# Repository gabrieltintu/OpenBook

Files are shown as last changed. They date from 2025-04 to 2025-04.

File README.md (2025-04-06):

## © 2025 Gabriel-Claudiu TINTU

# OpenBook - E-Book Reader Project

## Table of Contents

1. [Block Diagram](#block-diagram)
2. [Bill of Materials (BOM)](#bill-of-materials-bom)
3. [Hardware Functionality and Components](#hardware-functionality-and-components)
   - [Main Controller](#main-controller)
   - [Display System](#display-system)
   - [Power Management](#power-management)
   - [Memory and Storage](#memory-and-storage)
   - [Sensors and Timing](#sensors-and-timing)
   - [Connectivity](#connectivity)
4. [ESP32-C6 Pin Usage](#esp32-c6-pin-usage)
5. [3D Representation](#3d-representation)

## Block Diagram

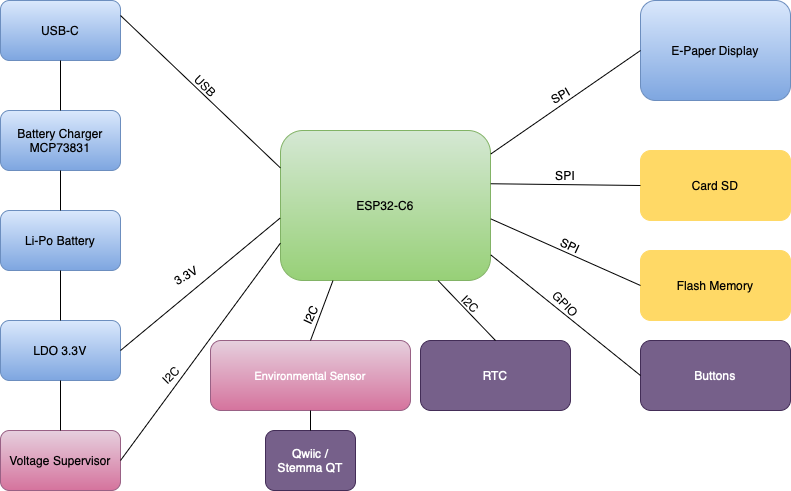
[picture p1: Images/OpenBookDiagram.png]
Block Diagram


## Bill of Materials (BOM)
| Package | Parts | Datasheet | Supplier  |
|---|---|---|---|
| ADAFRUIT_CHIP-LED0603 | CHG_LED | [Link](https://eu.mouser.com/datasheet/2/216/AP1608SURCK-71562.pdf) | [Link](https://eu.mouser.com/ProductDetail/Kingbright/AP1608SURCK?qs=VdjlWU%2FzoOEvYrd0H0exvQ%3D%3D) |
| SJ | SJ1 | [Link](https://grabcad.com/library/solder-jumpers-1) | [Link](https://grabcad.com/library/solder-jumpers-1) |
| ESP32_WROVER_EAGLE-LTSPICE_R0402 | R1_PWRUSB, R1, R1_PINH1, R2-PINH, R2-PINH1, R5, R6, R7, R8, R9, R10, R_BOOT, R_CL1, R_RESET, R3, R1_PINH, R4, R_CHANGE, R_CAPACITOR, R2, R1_BAT, R2_BAT, R2_USB, R2_USB1 | [Link](https://eu.mouser.com/datasheet/2/447/YAGEO_PYu_RC_Group_51_RoHS_L_12-3313492.pdf) | [Link](https://eu.mouser.com/ProductDetail/YAGEO/RC0402FR-07100KL?qs=mnq%2FyloZIXzTlUn7JAHSWg%3D%3D) |
| ESP32_WROVER_EAGLE-LTSPICE_C0402 | C1, C2, C4_USB, C6, C8, C9, C10, C_DELAY, EPD_C5, EPD_C1, EPD_C2, EPD_C6, EPD_C7, EPD_C8, EPD_C9, EPD_C10, EPD_C11, EPD_C12, C7, C5, C4, C1_BAT, C1_BAT1, C1_BAT2, C2_BAT, C5_USB | [Link](https://eu.mouser.com/datasheet/2/447/upy_gphc_x5r_4v_to_50v-3461255.pdf) | [Link](https://eu.mouser.com/ProductDetail/YAGEO/CC0402MRX5R5BB106?qs=zEY9bCHj09eCmUJdZuS5Lg%3D%3D) |
| RCL_CT3528 | C3 | [Link](https://eu.mouser.com/datasheet/2/40/TAJ-3165264.pdf) | [Link](https://eu.mouser.com/ProductDetail/KYOCERA-AVX/TAJB475K025RNJ?qs=mgX5NEyWO4Sl7CIvkz4Jiw%3D%3D) |
| 112ATAARR03ATTEND | J4 | [Link](https://store.comet.bg/download-file.php?id=27596) | [Link](https://store.comet.srl.ro/Catalogue/Product/43497/) |
| ESP32_WROVER_SPARKFUN-DISCRETESEMI_SOT23-3 | Q1, Q2 | [Link](https://www.diodes.com/assets/Datasheets/DMG2305UX.pdf) | [Link](https://eu.mouser.com/ProductDetail/Diodes-Incorporated/DMG2305UX-7?qs=L1DZKBg7t5F%2FNBHrjfxC%252Bg%3D%3D) |
| IND_4828-WE-TPC_WRE | L1 | [Link](https://www.we-online.com/components/products/datasheet/744043680.pdf) | [Link](https://eu.mouser.com/ProductDetail/Wurth-Elektronik/744043680?qs=PGXP4M47uW6VkZq%252BkzjrHA%3D%3D) |
| SOT95P280X125-5N | IC1 | [Link](https://fscdn.rohm.com/en/products/databook/datasheet/ic/power/voltage_detector/bd52xxg-e.pdf) | [Link](https://eu.mouser.com/ProductDetail/ROHM-Semiconductor/BD5229G-TR?qs=4kLU8WoGk0vvnhrrYwdszw%3D%3D) |
| MYBUTTON | BOOT_BUTTON, CHANGE_BUTTON, RESET_BUTTON | [Link](https://www3.panasonic.biz/ac/e_download/control/switch/light-touch/catalog/sw_lt_eng_3529s_side.pdf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) | [Link](https://eu.mouser.com/ProductDetail/Panasonic/EVQ-P7L01P?qs=rJ%252BziJWpyszWhhNszc02jQ%3D%3D) |
| CAPCP3225X100N | C10_SUPERCAP | [Link](https://eu.mouser.com/datasheet/2/360/Seiko_Instruments_MicroBattery_E_20230330_2024Jan_-3561061.pdf) | [Link](https://eu.mouser.com/ProductDetail/Seiko-Semiconductors/CPH3225A?qs=3etwrb1wR%252BhUOph6lAO7eg%3D%3D) |
| SOIC127P1032X265-16N | U3 | [Link](https://eu.mouser.com/datasheet/2/609/DS3231-3421123.pdf) | [Link](https://eu.mouser.com/ProductDetail/Analog-Devices-Maxim-Integrated/DS3231SN?qs=1eQvB6Dk1vhUlr8%2FOrV0Fw%3D%3D) |
| XCVR_ESP32-C6-WROOM-1-N8 | U2 | [Link](https://eu.mouser.com/datasheet/2/891/Espressif_ESP32_C6_WROOM_1__Datasheet_V0_1_PRELIMI-3239987.pdf) | [Link](https://eu.mouser.com/ProductDetail/Espressif-Systems/ESP32-C6-WROOM-1-N8?qs=8Wlm6%252BaMh8ST02Gmwp74cw%3D%3D) |
| ESP32C6_VARISTOR_CT/CN1812 | PFMF.050.1 | [Link](https://eu.mouser.com/datasheet/2/358/typ_PFMF-1275918.pdf) | [Link](https://eu.mouser.com/ProductDetail/Schurter/PFMF.050.2?qs=1auRipcfynCums5v1iucSA%3D%3D) |
| ESP32_WROVER_AVX---SD0805S020S1R0_AVX_SD0805S020S1R0_0 | D2, D7 | [Link](https://eu.mouser.com/datasheet/2/40/schottky-3165252.pdf) | [Link](https://eu.mouser.com/ProductDetail/KYOCERA-AVX/SD0805S020S1R0?qs=jCA%252BPfw4LHbpkAoSnwrdjw%3D%3D) |
| ESP32_WROVER_BME680_PSON80P300X300X100-8N | SENSOR2 | [Link](https://www.bosch-sensortec.com/media/boschsensortec/downloads/datasheets/bst-bme680-ds001.pdf) | [Link](https://store.comet.srl.ro/Catalogue/Product/50164/) |
| ESP32_WROVER_SPARKFUN-IC-POWER_SOT23-5 | U0 | [Link](https://eu.mouser.com/datasheet/2/268/MCP73831_Family_Data_Sheet_DS20001984H-3441711.pdf) | [Link](https://eu.mouser.com/ProductDetail/Microchip-Technology/MCP73831T-4ADI-OT?qs=hH%252BOa0VZEiBTiqxSV9eepQ%3D%3D) |
| FH34SRJ24S05SH99 | J1 | [Link](https://eu.mouser.com/datasheet/2/760/xc6220-3371556.pdf) | [Link](https://eu.mouser.com/ProductDetail/Torex-Semiconductor/XC6220A331MR-G?qs=AsjdqWjXhJ8ZSWznL1J0gg%3D%3D) |
| SON50P200X200X80-9N | U4 | [Link](https://eu.mouser.com/datasheet/2/609/MAX17048_MAX17049-3469099.pdf) | [Link](https://eu.mouser.com/ProductDetail/Analog-Devices-Maxim-Integrated/MAX17048G%2bT10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) |
| SOD3716X135N | D3, D4, D5 | [Link](https://eu.mouser.com/datasheet/2/40/schottky-3165252.pdf) | [Link](https://eu.mouser.com/ProductDetail/KYOCERA-AVX/SD0805S020S1R0?qs=jCA%252BPfw4LHbpkAoSnwrdjw%3D%3D) |
| DIOC1608X36N | D6, D8, D9, D10, D11, D12 | [Link](https://www.littelfuse.com/assetdocs/pulseguard-esd-suppressors-pgb1-datasheet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) | [Link](https://eu.mouser.com/ProductDetail/Littelfuse/PGB1010603MR?qs=gu7KAQ731URLg4GSnNNN7Q%3D%3D) |
| JST04_1MM_RA | J3 | [Link](https://eu.mouser.com/datasheet/2/813/Qwiic_Connector_Datasheet-1223982.pdf) | [Link](https://eu.mouser.com/ProductDetail/SparkFun/PRT-14417?qs=wd5RIQLrsJhgdz%2FpmZ%2F3GQ%3D%3D) |
| SAMACSYS_PARTS_USB4110GFA | J2 | [Link](https://eu.mouser.com/datasheet/2/837/GCT_USB4110_Product_Drawing___20k_cycles-3455479.pdf) | [Link](https://eu.mouser.com/ProductDetail/GCT/USB4110-GF-A?qs=KUoIvG%2F9IlYiZvIXQjyJeA%3D%3D) |
| SOT65P210X110-3N | Q3 | [Link](https://www.vishay.com/doc?63399) | [Link](https://eu.mouser.com/ProductDetail/Vishay-Semiconductors/SI1308EDL-T1-GE3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) |
| SOT95P280X145-6N | D1 | [Link](https://eu.mouser.com/datasheet/2/389/usblc6_2sc6y-1852505.pdf) | [Link](https://eu.mouser.com/ProductDetail/STMicroelectronics/USBLC6-2SC6Y?qs=gNDSiZmRJS%2FOgDexvXkdow%3D%3D) |
| SON127P600X800X80-9N | U1 | [Link](https://eu.mouser.com/datasheet/2/949/Winbond_W25Q512JV_Datasheet-3240039.pdf) | [Link](https://eu.mouser.com/ProductDetail/Winbond/W25Q512JVEIQ?qs=l7cgNqFNU1jw6svr3at6tA%3D%3D) |
| SOT95P280X120-5N | IC4 | [Link](https://eu.mouser.com/datasheet/2/760/xc6220-3371556.pdf) | [Link](https://eu.mouser.com/ProductDetail/Torex-Semiconductor/XC6220A331MR-G?qs=AsjdqWjXhJ8ZSWznL1J0gg%3D%3D) |

## Hardware Functionality and Components

### Main Controller

* ESP32-C6-WROOM-1-N8: The core microcontroller module that manages all device functions

### Display System

* E-Paper Display: Connected via a 24-pin FH34SRJ-24S-0.5SH connector (J1)
* E-Paper Drive Circuit: Custom circuitry for driving the e-paper display
* Display Type Selector: Allows for configuration of different e-paper display types

### Power Management

* LDO Voltage Regulator (XC6220A331MR-G): Provides regulated 3.3V power supply for the system
* Battery Charge Controller (MCP73831): Manages charging of the Li-Po battery
* Battery Charge Level Monitor (MAX17048G+T10): Monitors battery charge level and status
* USB C Connector: For power input and data communication
* ESD Protection (USBLC6-2SC6Y): Protects USB data lines from electrostatic discharge

### Memory and Storage

* External NOR Flash (W25Q512JVEIQ): 64MB flash memory for data storage
* SD Card Slot: For expandable storage

### Sensors and Timing

* Environmental Sensor (BME688): Measures temperature, humidity, pressure, and gas resistance
* RTC Module (DS3231SN): Real-time clock for accurate timekeeping

### Connectivity

* Qwiic/Stemma QT Connector: For I2C-based expansion modules
* USB-C: For data communication and power

## ESP32-C6 Pin Usage

| **Pin** | **Function** | **Component** | **Purpose** |
|-----|---|---|---|
| EN  | RESET | Reset button | System reset input |
| IO0 | INT_RTC | RTC | RTC interrupt for timing events |
| IO1 | 32KHZ | RTC | 32kHz clock signal from RTC |
| IO2 | MISO | SPI Bus | Data input from SPI peripherals |
| IO3 | EPD_BUSY | E-Paper Display | Monitor display ready status |
| IO4 | SS_SD | SD Card | SD card chip select |
| IO5 | EPD_DC | E-Paper Display | Display data/command selection |
| IO6 | SCK | SPI Bus | SPI clock signal |
| IO7 | MOSI | SPI Bus | Data output to SPI peripherals |
| IO8 | GPIO8 | General Purpose | Auxiliary functions |
| IO9 | IO/BOOT | Boot button | Boot mode selection |
| IO10 | EPD_CS | E-Paper Display | Display chip select |
| IO11 | FLASH_CS | External NOR Flash | Flash memory chip select |
| IO12 | USB_D- | USB Interface | USB data negative line |
| IO13 | USB_D+ | USB Interface | USB data positive line |
| IO15 | IO/CHANGE | Change button | Status change detection |
| IO16/TXD0 | TX | Serial Debug | UART transmit |
| IO17/RXD0 | RX | Serial Debug | UART receive |
| IO18 | RTC_RST | RTC | RTC reset control |
| IO19 | I2C_PW | I2C Bus | I2C devices power control |
| IO20 | EPD_3V3_C | E-Paper Display | Display power control |
| IO21 | SDA | I2C Bus | I2C data line |
| IO22 | SCL | I2C Bus | I2C clock line |
| IO23 | EPD_RST | E-Paper Display | Display reset control |

## 3D Representation

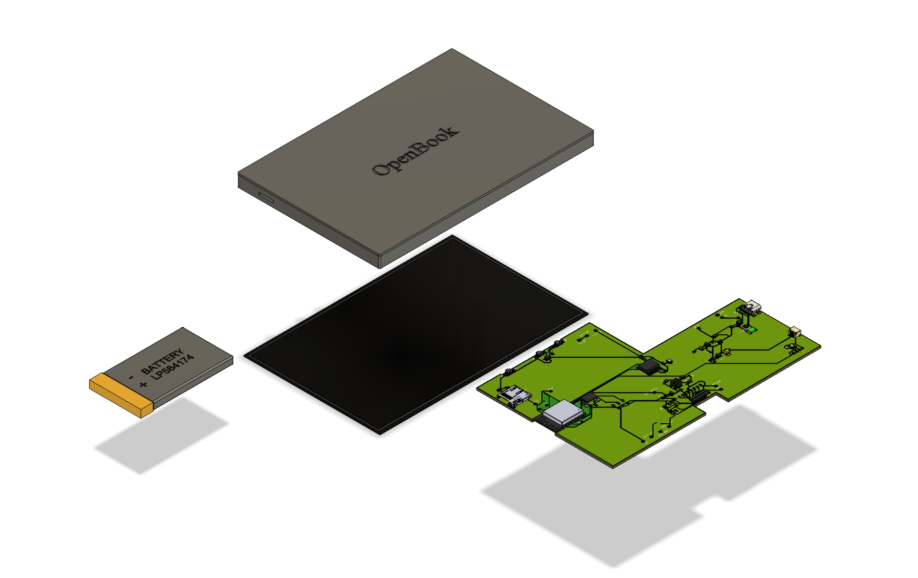
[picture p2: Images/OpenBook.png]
OpenBook


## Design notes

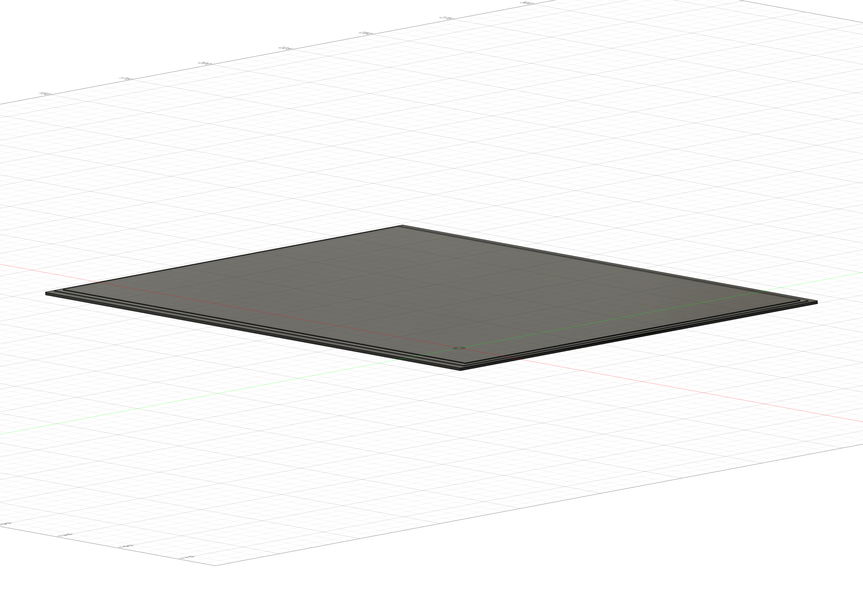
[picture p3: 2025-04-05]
Images/E-PAPER_DISPLAY_2.png

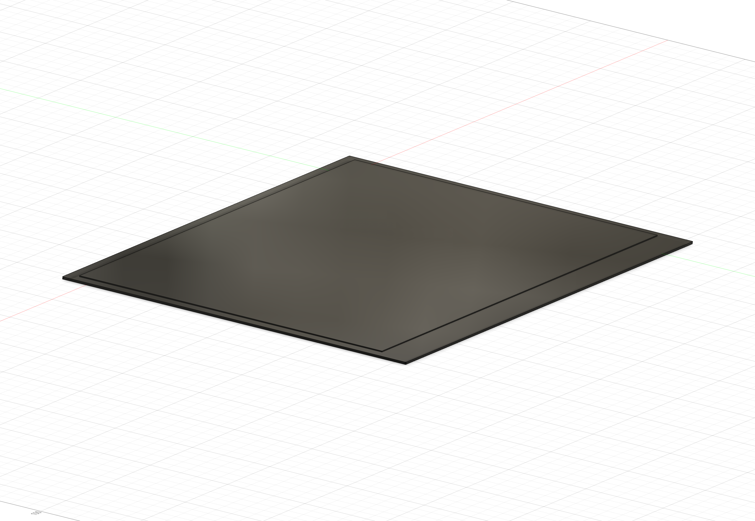
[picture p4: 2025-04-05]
Images/E-PAPER_DISPLAY_1.png

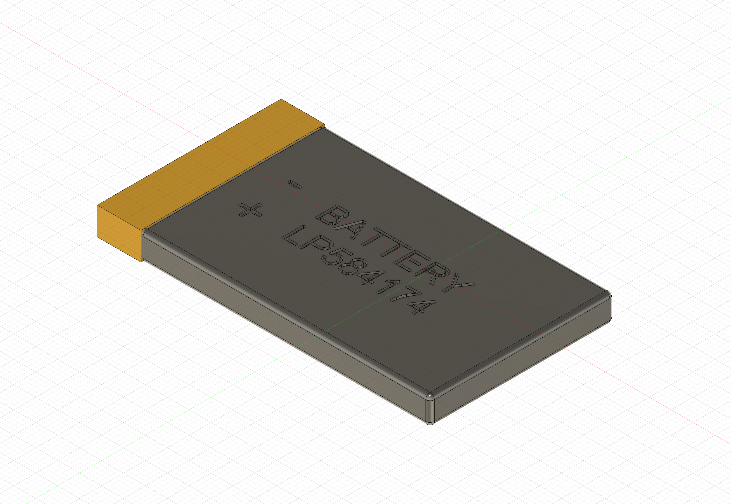
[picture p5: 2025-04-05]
Images/BATTERY_2.png

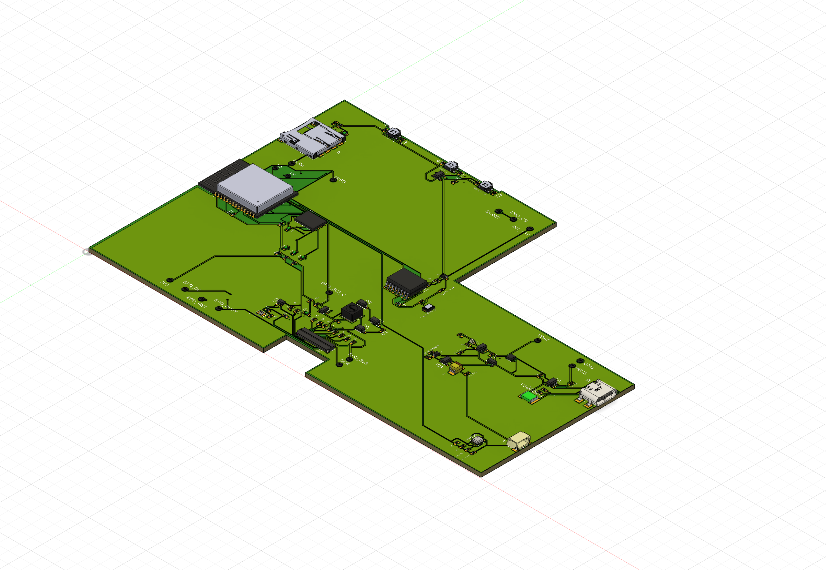
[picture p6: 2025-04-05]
Images/3D_PCB.png

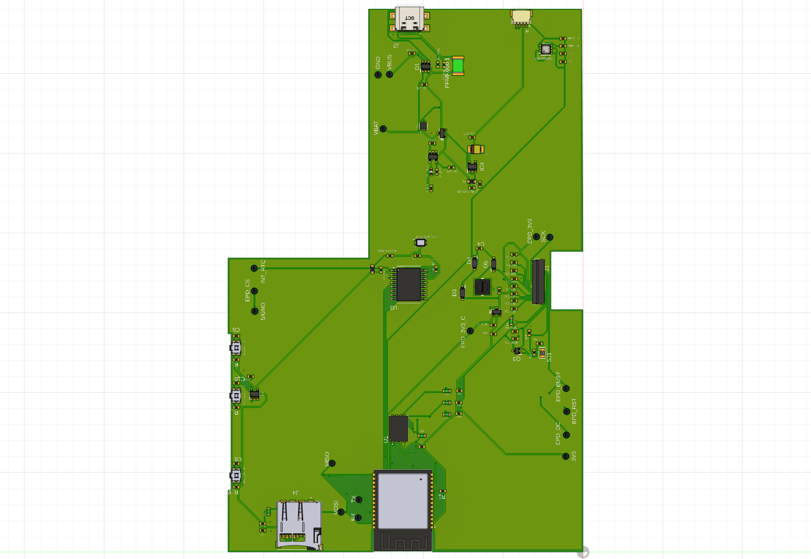
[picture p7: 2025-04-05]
Images/3D_PCB_4.png

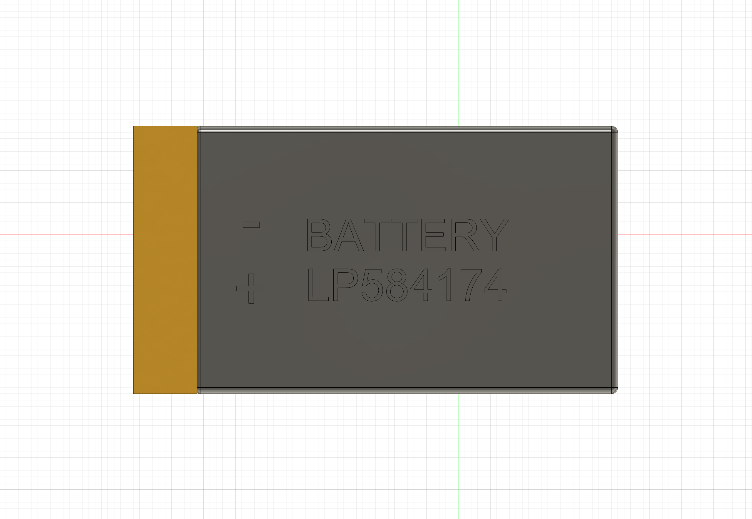
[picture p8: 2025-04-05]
Images/BATTERY_1.png

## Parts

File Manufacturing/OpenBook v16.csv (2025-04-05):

Qty | Value | Device | Package | Parts | Description | ARROW_PART_NUMBER | ARROW_PRICE-STOCK | AVAILABILITY | CENTROID_NOT_SPECIFIED | CHECK_PRICES | COPYRIGHT | DATASHEET | DESCRIPTION | DIGIKEY_DESCRIPTION | DIGIKEY_PART_NUMBER | HEIGHT | LEAD_FREE | MANUFACTURER_NAME | MANUFACTURER_PART_NUMBER | MF | MFR_NAME | MOUSER_PART_NUMBER | MOUSER_PRICE-STOCK | MOUSER_TESTING_PART_NUMBER | MOUSER_TESTING_PRICE-STOCK | MP | MPN | PACKAGE | POPULARITY | PREFIX | PRICE | PROD_ID | PURCHASE-URL | ROHS | SNAPEDA_LINK | SPICEMODEL | SPICEPREFIX | TEMPERATURE_RANGE_HIGH | TEMPERATURE_RANGE_LOW | TP_SIGNAL_NAME | VALUE
1 |  | ADAFRUIT_LEDCHIP-LED0603 | ADAFRUIT_CHIP-LED0603 | CHG_LED | LED
1 |  | SJ | SJ | SJ1 | SMD solder JUMPER |  |  |  |  |  |  |  |  |  |  |  |  |  |  |  |  |  |  |  |  |  |  |  | 3
1 | 0.1uF/50V | ESP32_WROVER_EAGLE-LTSPICE_CC0402 | ESP32_WROVER_EAGLE-LTSPICE_C0402 | EPD_C5 | CAPACITOR, European symbol |  |  |  |  |  |  |  |  |  |  |  |  |  |  |  |  |  |  |  |  |  |  |  |  |  |  |  |  |  |  | NONE | C
1 | 0.47 | ESP32_WROVER_EAGLE-LTSPICE_RR0402 | ESP32_WROVER_EAGLE-LTSPICE_R0402 | R3 | RESISTOR, European symbol |  |  |  |  |  |  |  |  |  |  |  |  |  |  |  |  |  |  |  |  |  |  |  |  |  |  |  |  |  |  | NONE | R
1 | 100K | ESP32_WROVER_EAGLE-LTSPICE_RR0402 | ESP32_WROVER_EAGLE-LTSPICE_R0402 | R1_PWRUSB | RESISTOR, European symbol |  |  |  |  |  |  |  |  |  |  |  |  |  |  |  |  |  |  |  |  |  |  |  |  |  |  |  |  |  |  | NONE | R
8 | 100nF | ESP32_WROVER_EAGLE-LTSPICE_CC0402 | ESP32_WROVER_EAGLE-LTSPICE_C0402 | C1, C2, C4_USB, C6, C8, C9, C10, C_DELAY | CAPACITOR, European symbol |  |  |  |  |  |  |  |  |  |  |  |  |  |  |  |  |  |  |  |  |  |  |  |  |  |  |  |  |  |  | NONE | C
1 | 100uF TANT | RCL_CPOL-EUCT3528 | RCL_CT3528 | C3 | POLARIZED CAPACITOR, European symbol |  |  |  |  |  |  |  |  |  |  |  |  |  |  |  |  |  |  |  |  |  |  |  | 0 |  |  |  |  |  |  |  | C
13 | 10K | ESP32_WROVER_EAGLE-LTSPICE_RR0402 | ESP32_WROVER_EAGLE-LTSPICE_R0402 | R1, R1_PINH1, R2-PINH, R2-PINH1, R5, R6, R7, R8, R9, R10, R_BOOT, R_CL1, R_RESET | RESISTOR, European symbol |  |  |  |  |  |  |  |  |  |  |  |  |  |  |  |  |  |  |  |  |  |  |  |  |  |  |  |  |  |  | NONE | R
1 | 10uF | ESP32_WROVER_EAGLE-LTSPICE_CC0402 | ESP32_WROVER_EAGLE-LTSPICE_C0402 | C7 | CAPACITOR, European symbol |  |  |  |  |  |  |  |  |  |  |  |  |  |  |  |  |  |  |  |  |  |  |  |  |  |  |  |  |  |  | NONE | C
1 | 112A-TAAR-R03_ATTEND | 112A-TAAR-R03_ATTEND | 112ATAARR03ATTEND | J4 | Micro SD Card Socket, Push-Push Type, Top Mount, SMT, H=1.83mm, 10u |  |  |  |  |  |  |  | Micro SD Card Socket | Push-Push Type | Top Mount | SMT | H=1.83mm | 10u |  |  | 1.9mm |  | ATTEND | 112A-TAAR-R03 ATTEND
1 | 15 | ESP32_WROVER_EAGLE-LTSPICE_RR0402 | ESP32_WROVER_EAGLE-LTSPICE_R0402 | R_CAPACITOR | RESISTOR, European symbol |  |  |  |  |  |  |  |  |  |  |  |  |  |  |  |  |  |  |  |  |  |  |  |  |  |  |  |  |  |  | NONE | R
3 | 1OK | ESP32_WROVER_EAGLE-LTSPICE_RR0402 | ESP32_WROVER_EAGLE-LTSPICE_R0402 | R1_PINH, R4, R_CHANGE | RESISTOR, European symbol |  |  |  |  |  |  |  |  |  |  |  |  |  |  |  |  |  |  |  |  |  |  |  |  |  |  |  |  |  |  | NONE | R
1 | 1uF | ESP32_WROVER_EAGLE-LTSPICE_CC0402 | ESP32_WROVER_EAGLE-LTSPICE_C0402 | C5 | CAPACITOR, European symbol |  |  |  |  |  |  |  |  |  |  |  |  |  |  |  |  |  |  |  |  |  |  |  |  |  |  |  |  |  |  | NONE | C
9 | 1uF/50V | ESP32_WROVER_EAGLE-LTSPICE_CC0402 | ESP32_WROVER_EAGLE-LTSPICE_C0402 | EPD_C1, EPD_C2, EPD_C6, EPD_C7, EPD_C8, EPD_C9, EPD_C10, EPD_C11, EPD_C12 | CAPACITOR, European symbol |  |  |  |  |  |  |  |  |  |  |  |  |  |  |  |  |  |  |  |  |  |  |  |  |  |  |  |  |  |  | NONE | C
1 | 2.2 | ESP32_WROVER_EAGLE-LTSPICE_RR0402 | ESP32_WROVER_EAGLE-LTSPICE_R0402 | R2 | RESISTOR, European symbol |  |  |  |  |  |  |  |  |  |  |  |  |  |  |  |  |  |  |  |  |  |  |  |  |  |  |  |  |  |  | NONE | R
1 | 200 | ESP32_WROVER_EAGLE-LTSPICE_RR0402 | ESP32_WROVER_EAGLE-LTSPICE_R0402 | R1_BAT | RESISTOR, European symbol |  |  |  |  |  |  |  |  |  |  |  |  |  |  |  |  |  |  |  |  |  |  |  |  |  |  |  |  |  |  | NONE | R
2 | 20V/4.2A/52mΩ/1.4W | ESP32_WROVER_SPARKFUN-DISCRETESEMI_MOSFET_PCH-DMG2305UX-7 | ESP32_WROVER_SPARKFUN-DISCRETESEMI_SOT23-3 | Q1, Q2 | P-channel MOSFETs |  |  |  |  |  |  |  |  |  |  |  |  |  |  |  |  |  |  |  |  |  |  |  |  |  |  | TRAN-14388 |  |  |  |  |  |  |  |  | 20V/4.2A/52mΩ/1.4W
1 | 2K | ESP32_WROVER_EAGLE-LTSPICE_RR0402 | ESP32_WROVER_EAGLE-LTSPICE_R0402 | R2_BAT | RESISTOR, European symbol |  |  |  |  |  |  |  |  |  |  |  |  |  |  |  |  |  |  |  |  |  |  |  |  |  |  |  |  |  |  | NONE | R
5 | 4.7uF | ESP32_WROVER_EAGLE-LTSPICE_CC0402 | ESP32_WROVER_EAGLE-LTSPICE_C0402 | C1_BAT, C1_BAT1, C1_BAT2, C2_BAT, C5_USB | CAPACITOR, European symbol |  |  |  |  |  |  |  |  |  |  |  |  |  |  |  |  |  |  |  |  |  |  |  |  |  |  |  |  |  |  | NONE | C
1 | 4.7uF/25V | ESP32_WROVER_EAGLE-LTSPICE_CC0402 | ESP32_WROVER_EAGLE-LTSPICE_C0402 | C4 | CAPACITOR, European symbol |  |  |  |  |  |  |  |  |  |  |  |  |  |  |  |  |  |  |  |  |  |  |  |  |  |  |  |  |  |  | NONE | C
2 | 5k1 | ESP32_WROVER_EAGLE-LTSPICE_RR0402 | ESP32_WROVER_EAGLE-LTSPICE_R0402 | R2_USB, R2_USB1 | RESISTOR, European symbol |  |  |  |  |  |  |  |  |  |  |  |  |  |  |  |  |  |  |  |  |  |  |  |  |  |  |  |  |  |  | NONE | R
1 | 744043680IND_4828-WE-TPC_WRE | 744043680IND_4828-WE-TPC_WRE | IND_4828-WE-TPC_WRE | L1 |  |  |  |  |  |  | Copyright (C) 2024 Ultra Librarian. All rights reserved. |  |  |  |  |  |  |  | 744043680 |  | Wurth Electronics
1 | BD5229G-TR | BD5229G-TR | SOT95P280X125-5N | IC1 | Voltage Detector with Adjustable Delay Time: CMOS processes are utilized to develop high precision, low current consumption CMOS reset ICs that allow arbitrary setting of the delay time. The extensive lineup includes both Nch Open Drain and CMOS output types in a wide range of detection voltages (from 2.3V to 6.0V, in 0.1V steps), enabling selection of the ideal solution based on customer requirements. In addition, the entire series is of course both lead-free and RoHS-compliant. |  |  |  |  |  |  |  | Voltage Detector with Adjustable Delay Time: CMOS processes are utilized to develop high precision | low current consumption CMOS reset ICs that allow arbitrary setting of the delay time. The extensive lineup includes both Nch Open Drain and CMOS output types in a wide range of detection voltages (from 2.3V to 6.0V | in 0.1V steps) | enabling selection of the ideal solution based on customer requirements. In addition | the entire series is of course both lead-free and RoHS-compliant. |  |  | 1.25mm |  | ROHM Semiconductor | BD5229G-TR |  |  | 755-BD5229G-TR | https://www.mouser.co.uk/ProductDetail/ROHM-Semiconductor/BD5229G-TR?qs=4kLU8WoGk0vvnhrrYwdszw%3D%3D
3 | BUTTON_CUSYOMV1 | BUTTON_CUSYOMV1 | MYBUTTON | BOOT_BUTTON, CHANGE_BUTTON, RESET_BUTTON
1 | CPH3225A | CPH3225A | CAPCP3225X100N | C10_SUPERCAP | Cap 0.011F 3.3V 1210 Flat Check availability |  |  | Not in stock |  | https://www.snapeda.com/parts/CPH3225A/Seiko+Instruments/view-part/?ref=eda |  |  | 11 mF (EDLC) Supercapacitor 3.3 V 1210 (3225 Metric) - - |  |  |  |  |  |  | Seiko Instruments |  |  |  |  |  | CPH3225A |  | 1210 Seiko |  |  | None |  | https://www.snapeda.com/api/url_track_click_mouser/?unipart_id=562593&manufacturer=Seiko Instruments&part_name=CPH3225A&search_term=None |  | https://www.snapeda.com/parts/CPH3225A/Seiko+Instruments/view-part/?ref=snap
1 | DS3231SN# | DS3231SN# | SOIC127P1032X265-16N | U3 | Real Time Clock Serial 16-Pin SOIC W T/R Check availability |  |  | In Stock |  | https://www.snapeda.com/parts/DS3231SN%23/Analog+Devices/view-part/?ref=eda |  |  | Extremely Accurate I²C-Integrated RTC/TCXO/Crystal |  |  |  |  |  |  | Analog Devices |  |  |  |  |  | DS3231SN# |  | SOIC-16 Maxim |  |  | None |  | https://www.snapeda.com/api/url_track_click_mouser/?unipart_id=99048&manufacturer=Analog Devices&part_name=DS3231SN#&search_term=None |  | https://www.snapeda.com/parts/DS3231SN%23/Analog+Devices/view-part/?ref=snap
1 | ESP32-C6-WROOM-1-N8 | ESP32-C6-WROOM-1-N8 | XCVR_ESP32-C6-WROOM-1-N8 | U2 | Check availability |  |  | In Stock |  | https://www.snapeda.com/parts/ESP32-C6-WROOM-1-N8/Espressif+Systems/view-part/?ref=eda |  |  | Multiprotocol Modules ESP32-C6 module | Wi-Fi 6 in 2.4 GHz band | Bluetooth 5 | Zigbee 3.0 and Thread. ESP34-WROOM Compatible - ENGINEERING SAMPLE |  |  |  |  |  |  | Espressif Systems |  |  |  |  |  | ESP32-C6-WROOM-1-N8 |  | None |  |  | None |  |  |  | https://www.snapeda.com/parts/ESP32-C6-WROOM-1-N8/Espressif+Systems/view-part/?ref=snap
1 | ESP32C6_VARISTORCN1812 | ESP32C6_VARISTORCN1812 | ESP32C6_VARISTOR_CT/CN1812 | PFMF.050.1 | VARISTOR |  |  |  |  |  |  |  |  |  |  |  |  |  |  |  |  |  |  |  |  |  |  |  | 0
2 | ESP32_WROVER_AVX---SD0805S020S1R0_AVX_SD0805S020S1R0_0_0AVX_SD0805S020S1R0_0_0 | ESP32_WROVER_AVX---SD0805S020S1R0_AVX_SD0805S020S1R0_0_0AVX_SD0805S020S1R0_0_0 | ESP32_WROVER_AVX---SD0805S020S1R0_AVX_SD0805S020S1R0_0 | D2, D7 | Schottky Barrier Rectifier Diode |  |  |  | No |  |  | http://datasheets.avx.com/schottky.pdf |  | DIODE SCHOTTKY 20V 1A 0805 | 478-7800-1-ND |  | yes |  |  | AVX |  | 581-SD0805S020S1R0 |  |  |  |  |  | 0805 (2012 metric) |  | D |  |  |  | yes |  |  |  | +125°C | -55°C
1 | ESP32_WROVER_BME680_BME680 | ESP32_WROVER_BME680_BME680 | ESP32_WROVER_BME680_PSON80P300X300X100-8N | SENSOR2 | Integrated Environmental Unit |  |  | Unavailable |  |  |  |  | Integrated Environmental Unit |  |  |  |  |  |  | Bosch Sensortec |  |  |  |  |  | BME680 |  | LGA-8 Bosch Tools |  |  | None
1 | ESP32_WROVER_SPARKFUN-IC-POWER_MCP73831 | ESP32_WROVER_SPARKFUN-IC-POWER_MCP73831 | ESP32_WROVER_SPARKFUN-IC-POWER_SOT23-5 | U0 | MCP73831T Li-Ion, Li-Pol Controller |  |  |  |  |  |  |  |  |  |  |  |  |  |  |  |  |  |  |  |  |  |  |  |  |  |  | IC-09995
1 | FH34SRJ-24S-0.5SH_99_ | FH34SRJ-24S-0.5SH_99_ | FH34SRJ24S05SH99 | J1 | (0.50mm) Surface Mount, Right Angle |  |  |  |  |  |  |  | 24 Position FFC | FPC Connector Contacts | (0.50mm) Surface Mount | Right Angle |  |  | 1.1mm |  | Hirose | FH34SRJ-24S-0.5SH(99) |  |  | 798-FH34SRJ24S05SH99 | https://www.mouser.co.uk/ProductDetail/Hirose-Connector/FH34SRJ-24S-0.5SH99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
1 | MAX17048G+T10 | MAX17048G+T10 | SON50P200X200X80-9N | U4 | Check availability |  |  | In Stock |  | https://www.snapeda.com/parts/MAX17048G+T10/Analog+Devices/view-part/?ref=eda |  |  | 3µA 1-Cell/2-Cell Fuel Gauge with ModelGauge |  |  |  |  |  |  | Analog Devices |  |  |  |  |  | MAX17048G+T10 |  | TDFN-8 Maxim |  |  | None |  | https://www.snapeda.com/api/url_track_click_mouser/?unipart_id=329239&manufacturer=Analog Devices&part_name=MAX17048G+T10&search_term=None |  | https://www.snapeda.com/parts/MAX17048G+T10/Analog+Devices/view-part/?ref=snap
3 | MBR0530 | MBR0530 | SOD3716X135N | D3, D4, D5 | ON SEMICONDUCTOR - MBR0530 - DIODE, SCHOTTKY, 0.5A, 30V, SOD-123 |  |  | In Stock |  | https://www.snapeda.com/parts/MBR0530/Onsemi/view-part/?ref=eda |  |  | Diode Schottky 30 V 500mA Surface Mount SOD-123 |  |  |  |  |  |  | ON Semiconductor |  |  |  |  |  | MBR0530 |  | SOD-123-2 ON Semiconductor |  |  | None |  | https://www.snapeda.com/api/url_track_click_mouser/?unipart_id=179458&manufacturer=ON Semiconductor&part_name=MBR0530&search_term=None |  | https://www.snapeda.com/parts/MBR0530/Onsemi/view-part/?ref=snap
6 | PGB1010603MR | PGB1010603MR | DIOC1608X36N | D6, D8, D9, D10, D11, D12 | Check availability |  |  | In Stock |  | https://www.snapeda.com/parts/PGB1010603MR/Littelfuse/view-part/?ref=eda |  |  | 150V (Typ) Clamp - Ipp Tvs Diode Surface Mount 0603 (1608 Metric) |  |  |  |  |  |  | Littelfuse Inc. |  |  |  |  |  | PGB1010603MR |  | 0603 Littelfuse Inc. |  |  | None |  | https://www.snapeda.com/api/url_track_click_mouser/?unipart_id=5659453&manufacturer=Littelfuse Inc.&part_name=PGB1010603MR&search_term=None |  | https://www.snapeda.com/parts/PGB1010603MR/Littelfuse/view-part/?ref=snap
1 | QWIIC_RIGHT_ANGLE | QWIIC_CONNECTORJS-1MM | JST04_1MM_RA | J3 | SparkFun I2C Standard Qwiic Connector |  |  |  |  |  |  |  |  |  |  |  |  |  |  |  |  |  |  |  |  |  |  |  |  |  |  | CONN-13694 |  |  |  |  |  |  |  |  | QWIIC_RIGHT_ANGLE
1 | SAMACSYS_PARTS_USB4110-GF-A | SAMACSYS_PARTS_USB4110-GF-A | SAMACSYS_PARTS_USB4110GFA | J2 | CONN USB 2.0 TYPE-C R/A SMT |  |  |  |  |  |  |  | CONN USB 2.0 TYPE-C R/A SMT |  |  | 3.26mm |  | GCT (GLOBAL CONNECTOR TECHNOLOGY) | USB4110-GF-A |  |  | 640-USB4110-GF-A | https://www.mouser.co.uk/ProductDetail/GCT/USB4110-GF-A?qs=KUoIvG%2F9IlYiZvIXQjyJeA%3D%3D
1 | SI1308EDL-T1-GE3 | SI1308EDL-T1-GE3 | SOT65P210X110-3N | Q3 | MOSFET N-Ch 30V 1.5A TrenchFET SC70 Vishay Si1308EDL-T1-GE3 N-channel MOSFET Transistor, 1.5 A, 30 V, 3-Pin SC-70 |  |  | In Stock |  | https://www.snapeda.com/parts/SI1308EDL-T1-GE3/Vishay+Siliconix/view-part/?ref=eda |  |  | Si1308EDL-T1-GE3 N-channel MOSFET Transistor | 1.5 A | 30 V | 3-Pin SC-70 | Siliconix / Vishay SI1308EDL-T1-GE3 |  |  |  |  |  |  | Vishay Siliconix |  |  |  |  |  | SI1308EDL-T1-GE3 |  | SOT-323 Vishay Semiconductor |  |  | None |  | https://www.snapeda.com/api/url_track_click_mouser/?unipart_id=274603&manufacturer=Vishay Siliconix&part_name=SI1308EDL-T1-GE3&search_term=None |  | https://www.snapeda.com/parts/SI1308EDL-T1-GE3/Vishay+Siliconix/view-part/?ref=snap
17 | TPTP20R | TPTP20R | TP20R | 3V3, 5/GND, EPD_3V3, EPD_3V3_C, EPD_BUSY, EPD_CS, EPD_DC, EPD_RST, GND, INT_RTC, MISO, MOSI, RX, SCK, TX, VBAT, VBUS | Test pad |  |  |  |  |  |  |  |  |  |  |  |  |  |  |  |  |  |  |  |  |  |  |  | 2
1 | USBLC6-2SC6Y | USBLC6-2SC6Y | SOT95P280X145-6N | D1 | Low Cap. ESD Protection Auto SOT-23-6 STMicroelectronics USBLC6-2SC6Y, Dual Uni-Directional TVS Diode Array, 6-Pin SOT-23 |  |  | In Stock |  | https://www.snapeda.com/parts/USBLC6-2SC6Y/STMicroelectronics/view-part/?ref=eda |  |  | 17V Clamp 5A (8/20µs) Ipp Tvs Diode Surface Mount SOT-23-6 |  |  |  |  |  |  | STMicroelectronics |  |  |  |  |  | USBLC6-2SC6Y |  | SOT-23-6 STMicroelectronics |  |  | None |  |  |  | https://www.snapeda.com/parts/USBLC6-2SC6Y/STMicroelectronics/view-part/?ref=snap
1 | W25Q512JVEIQ | W25Q512JVEIQ | SON127P600X800X80-9N | U1 | Check availability |  |  | In Stock |  | https://www.snapeda.com/parts/W25Q512JVEIQ/Winbond+Electronics/view-part/?ref=eda |  |  | FLASH - NOR Memory IC 512Mb (64M x 8) SPI - Quad I/O 133 MHz 8-WSON (8x6) |  |  |  |  |  |  | Winbond Electronics |  |  |  |  |  | W25Q512JVEIQ |  | Package |  |  | None |  |  |  | https://www.snapeda.com/parts/W25Q512JVEIQ/Winbond+Electronics/view-part/?ref=snap
1 | XC6220A331MR-G | XC6220A331MR-G | SOT95P280X120-5N | IC4 | LDO Voltage Regulators |  |  |  |  |  |  |  | LDO Voltage Regulators |  |  | 1.2mm |  | Torex | XC6220A331MR-G |  |  | 865-XC6220A331MR-G | https://www.mouser.co.uk/ProductDetail/Torex-Semiconductor/XC6220A331MR-G?qs=AsjdqWjXhJ8ZSWznL1J0gg%3D%3D

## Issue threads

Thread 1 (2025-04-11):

Fix unfilled areas in GND plane

madalinserbu, 2025-04-11:

Closed 2025-04-14.

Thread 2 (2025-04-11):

Fix PCB Thickness

madalinserbu, 2025-04-11:

Closed 2025-04-14.

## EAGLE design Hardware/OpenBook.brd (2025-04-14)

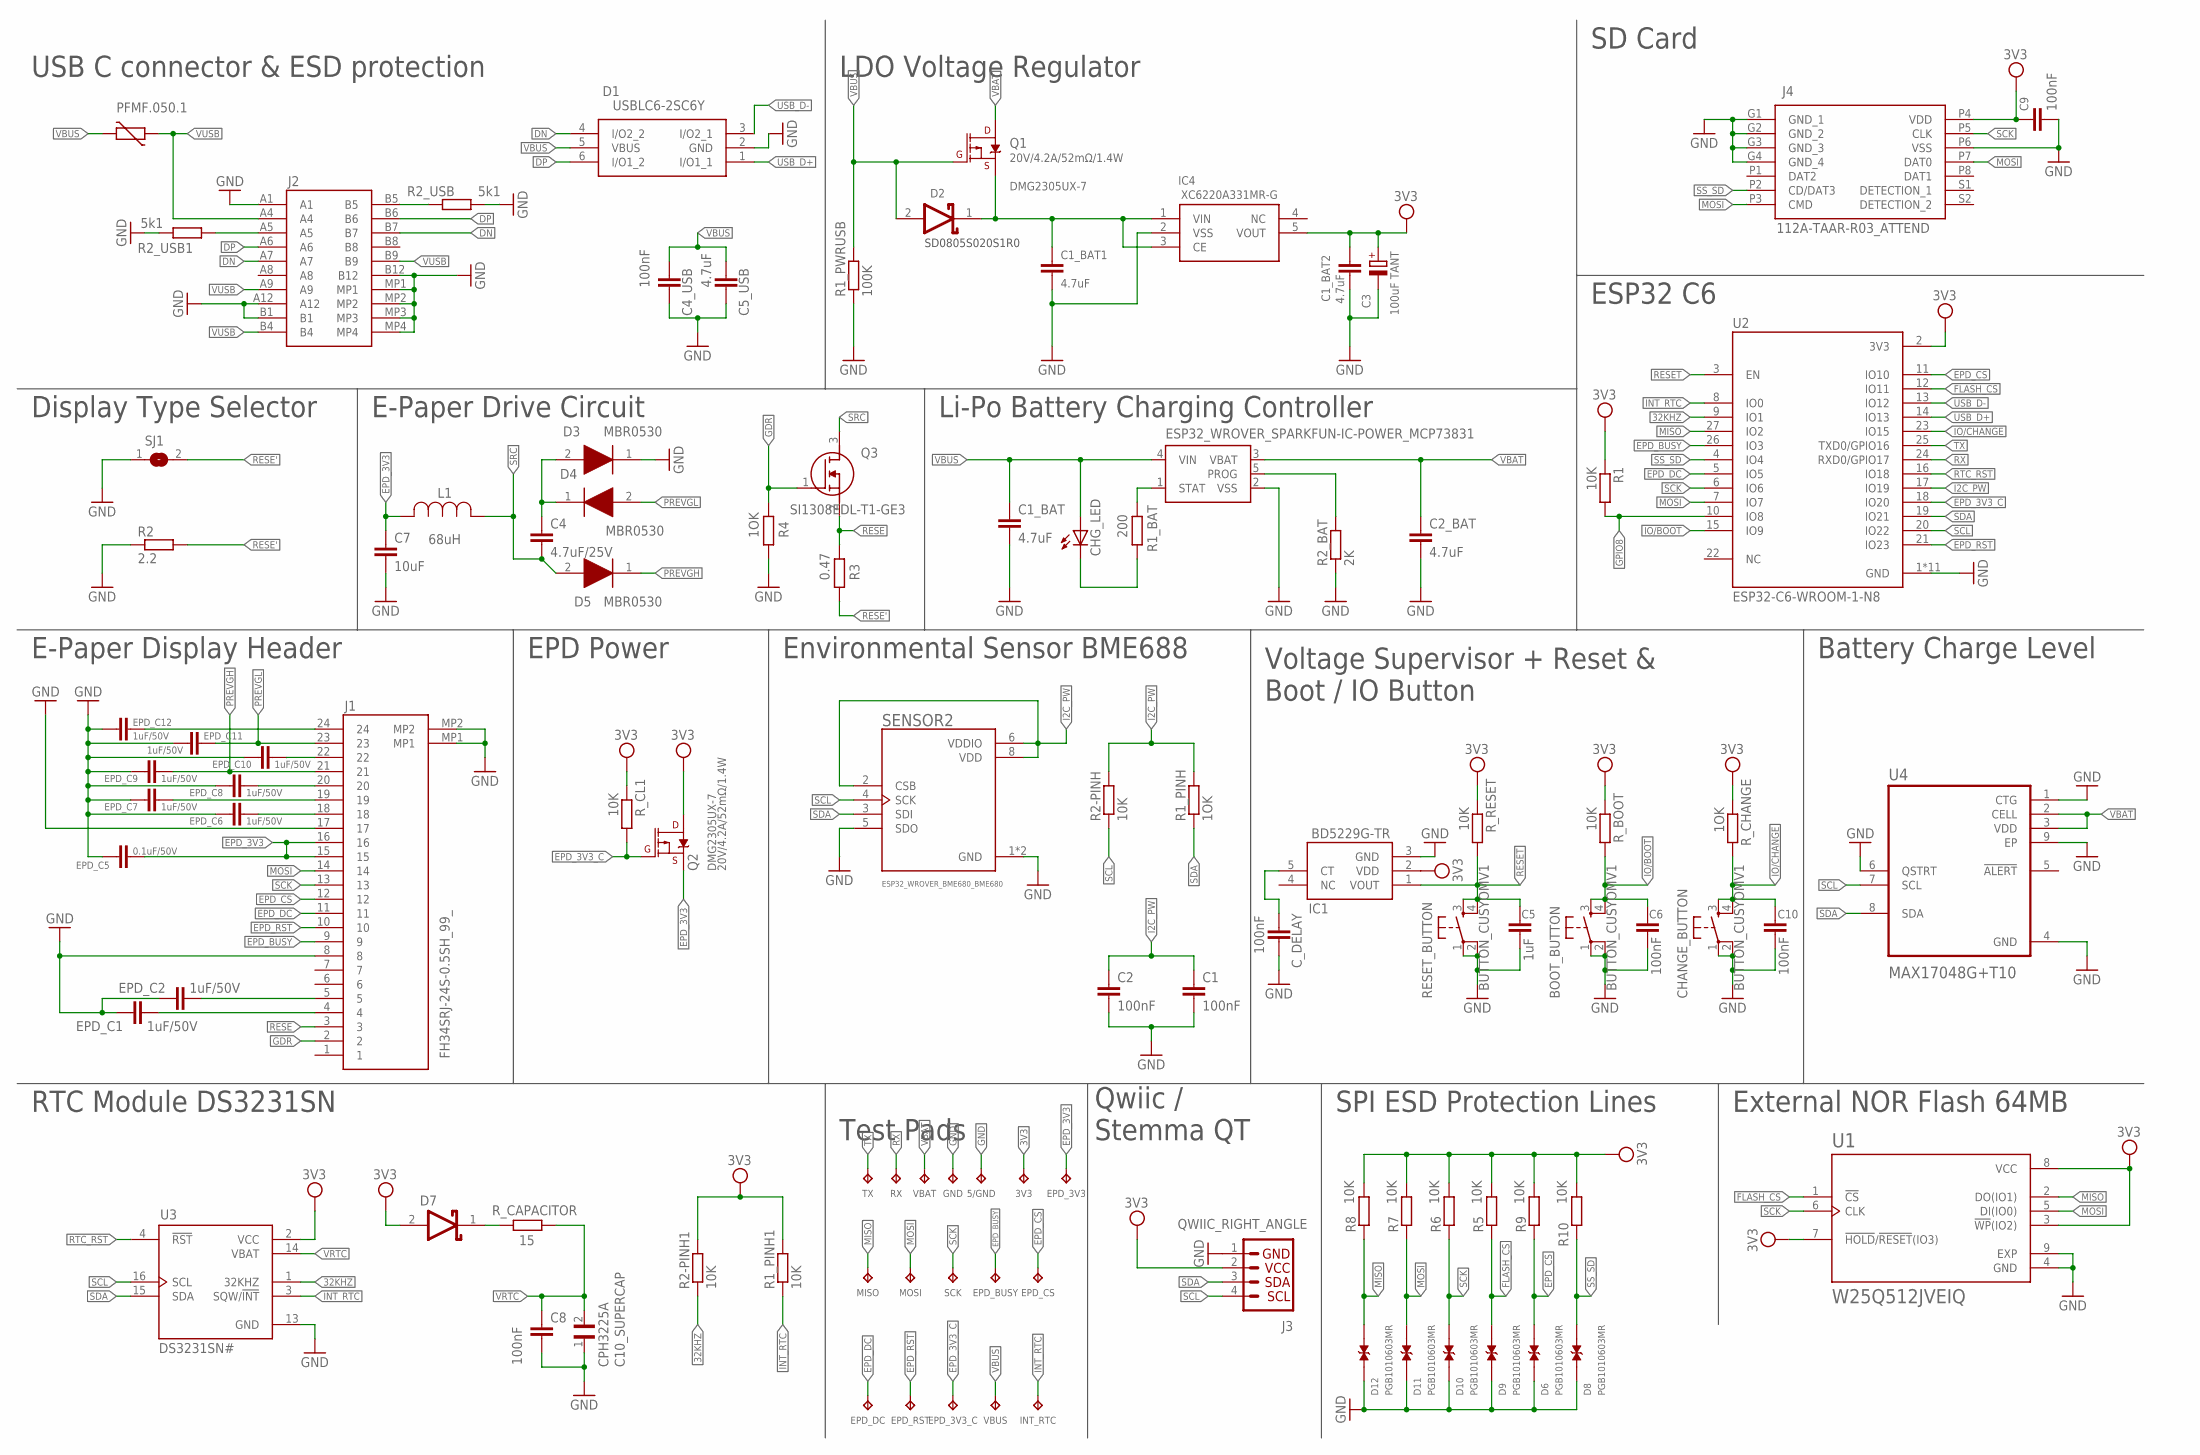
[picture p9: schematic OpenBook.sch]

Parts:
3V3, 5/GND: TPTP20R; TP20R
BOOT_BUTTON: BUTTON_CUSYOMV1; MYBUTTON
C1, C2, C4_USB, C6, C8, C9, C10: 100nF; ESP32_WROVER_EAGLE-LTSPICE_C0402
C1_BAT, C1_BAT1, C1_BAT2, C2_BAT, C5_USB: 4.7uF; ESP32_WROVER_EAGLE-LTSPICE_C0402
C3: 100uF TANT; RCL_CT3528
C4: 4.7uF/25V; ESP32_WROVER_EAGLE-LTSPICE_C0402
C5: 1uF; ESP32_WROVER_EAGLE-LTSPICE_C0402
C7: 10uF; ESP32_WROVER_EAGLE-LTSPICE_C0402
C10_SUPERCAP: CPH3225A; CAPCP3225X100N
CHANGE_BUTTON: BUTTON_CUSYOMV1; MYBUTTON
CHG_LED: ADAFRUIT_LEDCHIP-LED0603; ADAFRUIT_CHIP-LED0603
C_DELAY: 100nF; ESP32_WROVER_EAGLE-LTSPICE_C0402
D1: USBLC6-2SC6Y; SOT95P280X145-6N
D2, D7: ESP32_WROVER_AVX---SD0805S020S1R0_AVX_SD0805S020S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; ESP32_WROVER_AVX---SD0805S020S1R0_AVX_SD0805S020S1R0_0
D3, D4, D5: MBR0530; SOD3716X135N
D6, D8, D9, D10, D11, D12: PGB1010603MR; DIOC1608X36N
EPD_3V3, EPD_3V3_C: TPTP20R; TP20R
EPD_BUSY: TPTP20R; TP20R
EPD_C1, EPD_C2, EPD_C6, EPD_C7, EPD_C8, EPD_C9, EPD_C10, EPD_C11, EPD_C12: 1uF/50V; ESP32_WROVER_EAGLE-LTSPICE_C0402
EPD_C5: 0.1uF/50V; ESP32_WROVER_EAGLE-LTSPICE_C0402
EPD_CS: TPTP20R; TP20R
EPD_DC: TPTP20R; TP20R
EPD_RST: TPTP20R; TP20R
GND: TPTP20R; TP20R
IC1: BD5229G-TR; SOT95P280X125-5N
IC4: XC6220A331MR-G; SOT95P280X120-5N
INT_RTC: TPTP20R; TP20R
J1: FH34SRJ-24S-0.5SH_99_; FH34SRJ24S05SH99
J2: SAMACSYS_PARTS_USB4110-GF-A; SAMACSYS_PARTS_USB4110GFA
J3: QWIIC_RIGHT_ANGLE; JST04_1MM_RA
J4: 112A-TAAR-R03_ATTEND; 112ATAARR03ATTEND
L1: 744043680IND_4828-WE-TPC_WRE; IND_4828-WE-TPC_WRE
MISO: TPTP20R; TP20R
MOSI: TPTP20R; TP20R
PFMF.050.1: ESP32C6_VARISTORCN1812; ESP32C6_VARISTOR_CT/CN1812
Q1, Q2: 20V/4.2A/52mΩ/1.4W; ESP32_WROVER_SPARKFUN-DISCRETESEMI_SOT23-3
Q3: SI1308EDL-T1-GE3; SOT65P210X110-3N
R1, R1_PINH1, R2-PINH, R2-PINH1, R5, R6, R7, R8, R9, R10: 10K; ESP32_WROVER_EAGLE-LTSPICE_R0402
R1_BAT: 200; ESP32_WROVER_EAGLE-LTSPICE_R0402
R1_PINH, R4: 1OK; ESP32_WROVER_EAGLE-LTSPICE_R0402
R1_PWRUSB: 100K; ESP32_WROVER_EAGLE-LTSPICE_R0402
R2: 2.2; ESP32_WROVER_EAGLE-LTSPICE_R0402
R2_BAT: 2K; ESP32_WROVER_EAGLE-LTSPICE_R0402
R2_USB, R2_USB1: 5k1; ESP32_WROVER_EAGLE-LTSPICE_R0402
R3: 0.47; ESP32_WROVER_EAGLE-LTSPICE_R0402
RESET_BUTTON: BUTTON_CUSYOMV1; MYBUTTON
RX: TPTP20R; TP20R
R_BOOT: 10K; ESP32_WROVER_EAGLE-LTSPICE_R0402
R_CAPACITOR: 15; ESP32_WROVER_EAGLE-LTSPICE_R0402
R_CHANGE: 1OK; ESP32_WROVER_EAGLE-LTSPICE_R0402
R_CL1: 10K; ESP32_WROVER_EAGLE-LTSPICE_R0402
R_RESET: 10K; ESP32_WROVER_EAGLE-LTSPICE_R0402
SCK: TPTP20R; TP20R
SENSOR2: ESP32_WROVER_BME680_BME680; ESP32_WROVER_BME680_PSON80P300X300X100-8N
SJ1: SJ
TX: TPTP20R; TP20R
U0: ESP32_WROVER_SPARKFUN-IC-POWER_MCP73831; ESP32_WROVER_SPARKFUN-IC-POWER_SOT23-5
U1: W25Q512JVEIQ; SON127P600X800X80-9N
U2: ESP32-C6-WROOM-1-N8; XCVR_ESP32-C6-WROOM-1-N8
U3: DS3231SN#; SOIC127P1032X265-16N
U4: MAX17048G+T10; SON50P200X200X80-9N
VBAT: TPTP20R; TP20R
VBUS: TPTP20R; TP20R

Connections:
3V3: 3V3.TP, C1_BAT2.1, C3.+, C9.1, D7.2 (ANODE), IC1.2 (VDD), IC4.5 (VOUT), J3.2, J4.P4 (VDD), Q2.3 (D), R1.1, R1_PINH1.2, R2-PINH1.2, R5.2, R6.2, R7.2, R8.2, R9.2, R10.2, R_BOOT.1, R_CHANGE.1, R_CL1.1, R_RESET.1, U1.3 (!WP!(IO2)), U1.7 (!HOLD!/!RESET!(IO3)), U1.8 (VCC), U2.2 (3V3), U3.2 (VCC)
32KHZ: R2-PINH1.1, U2.9 (IO1), U3.1 (32KHZ)
DN: D1.4 (I/O2_2), J2.A7, J2.B7
DP: D1.6 (I/O1_2), J2.A6, J2.B6
EPD_3V3: C7.1, EPD_3V3.TP, EPD_C5.1, J1.15, J1.16, L1.2, Q2.2 (S)
EPD_3V3_C: EPD_3V3_C.TP, Q2.1 (G), R_CL1.2, U2.18 (IO20)
EPD_BUSY: EPD_BUSY.TP, J1.9, U2.26 (IO3)
EPD_CS: D6.2, EPD_CS.TP, J1.12, R9.1, U2.11 (IO10)
EPD_DC: EPD_DC.TP, J1.11, U2.5 (IO5)
EPD_RST: EPD_RST.TP, J1.10, U2.21 (IO23)
FLASH_CS: D9.2, R5.1, U1.1 (!CS), U2.12 (IO11)
GDR: J1.2, Q3.1 (G), R4.2
GND: 5/GND.TP, BOOT_BUTTON.1, BOOT_BUTTON.2, C1.2, C1_BAT.2, C1_BAT1.2, C1_BAT2.2, C2.2, C2_BAT.2, C3.-, C4_USB.2, C5.2, C5_USB.2, C6.2, C7.2, C8.2, C9.2, C10.2, C10_SUPERCAP.1, CHANGE_BUTTON.1, CHANGE_BUTTON.2, C_DELAY.2, D1.2 (GND), D4.1 (K), D6.1, D8.1, D9.1, D10.1, D11.1, D12.1, EPD_C1.2, EPD_C2.2, EPD_C5.2, EPD_C6.2, EPD_C7.2, EPD_C8.2, EPD_C9.2, EPD_C10.2, EPD_C11.2, EPD_C12.2, GND.TP, IC1.3 (GND), IC4.2 (VSS), J1.8, J1.17, J1.MP1, J1.MP2, J2.A1, J2.A12, J2.B1, J2.B12, J2.MP1, J2.MP2, J2.MP3, J2.MP4, J3.1, J4.G1 (GND_1), J4.G2 (GND_2), J4.G3 (GND_3), J4.G4 (GND_4), J4.P6 (VSS), R1_PWRUSB.1, R2.1, R2_BAT.1, R2_USB.2, R2_USB1.1, R4.1, RESET_BUTTON.1, RESET_BUTTON.2, SENSOR2.1 (GND), SENSOR2.5 (SDO), SENSOR2.7 (GND), SJ1.1, U0.2 (VSS), U1.4 (GND), U1.9 (EXP), U2.1 (GND), U2.28 (GND), U2.29_1 (GND), U2.29_2 (GND), U2.29_3 (GND), U2.29_4 (GND), U2.29_5 (GND), U2.29_6 (GND), U2.29_7 (GND), U2.29_8 (GND), U2.29_9 (GND), U3.13 (GND), U4.1 (CTG), U4.4 (GND), U4.6 (QSTRT), U4.9 (EP)
GPIO8: R1.2, U2.10 (IO8)
I2C_PW: C1.1, C2.1, R1_PINH.2, R2-PINH.2, SENSOR2.2 (CSB), SENSOR2.6 (VDDIO), SENSOR2.8 (VDD), U2.17 (IO19)
INT_RTC: INT_RTC.TP, R1_PINH1.1, U2.8 (IO0), U3.3 (SQW/!INT)
IO/BOOT: BOOT_BUTTON.3, BOOT_BUTTON.4, C6.1, R_BOOT.2, U2.15 (IO9)
IO/CHANGE: C10.1, CHANGE_BUTTON.3, CHANGE_BUTTON.4, R_CHANGE.2, U2.23 (IO15)
MISO: D12.2, MISO.TP, R8.1, U1.2 (DO(IO1)), U2.27 (IO2)
MOSI: D11.2, J1.14, J4.P3 (CMD), J4.P7 (DAT0), MOSI.TP, R7.1, U1.5 (DI(IO0)), U2.7 (IO7)
unnamed: J2.A5, R2_USB1.2
unnamed: J2.B5, R2_USB.1
unnamed: C1_BAT1.1, D2.1 (CATHODE), IC4.1 (VIN), IC4.3 (CE), Q1.2 (S)
unnamed: R1_BAT.2, U0.1 (STAT)
unnamed: C4.1, D3.1 (K), D4.2 (A)
unnamed: CHG_LED.C, R1_BAT.1
unnamed: D7.1 (CATHODE), R_CAPACITOR.2
unnamed: R2_BAT.2, U0.5 (PROG)
unnamed: EPD_C12.1, J1.24
unnamed: C_DELAY.1, IC1.5 (CT)
unnamed: EPD_C10.1, J1.22
unnamed: EPD_C7.1, J1.19
unnamed: EPD_C8.1, J1.20
unnamed: EPD_C6.1, J1.18
unnamed: EPD_C1.1, J1.4
unnamed: EPD_C2.1, J1.5
PREVGH: D5.1 (K), EPD_C9.1, J1.21
PREVGL: D3.2 (A), EPD_C11.1, J1.23
RESE: J1.3, Q3.2 (S), R3.2
RESE': R2.2, R3.1, SJ1.2
RESET: C5.1, IC1.1 (VOUT), RESET_BUTTON.3, RESET_BUTTON.4, R_RESET.2, U2.3 (EN)
RTC_RST: U2.16 (IO18), U3.4 (!RST)
RX: RX.TP, U2.24 (RXD0/GPIO17)
SCK: D10.2, J1.13, J4.P5 (CLK), R6.1, SCK.TP, U1.6 (CLK), U2.6 (IO6)
SCL: J3.4, R2-PINH.1, SENSOR2.4 (SCK), U2.20 (IO22), U3.16 (SCL), U4.7 (SCL)
SDA: J3.3, R1_PINH.1, SENSOR2.3 (SDI), U2.19 (IO21), U3.15 (SDA), U4.8 (SDA)
SRC: C4.2, D5.2 (A), L1.1, Q3.3 (D)
SS_SD: D8.2, J4.P2 (CD/DAT3), R10.1, U2.4 (IO4)
TX: TX.TP, U2.25 (TXD0/GPIO16)
USB_D+: D1.1 (I/O1_1), U2.14 (IO13)
USB_D-: D1.3 (I/O2_1), U2.13 (IO12)
VBAT: C2_BAT.1, Q1.3 (D), U0.3 (VBAT), U4.2 (CELL), U4.3 (VDD), VBAT.TP
VBUS: C1_BAT.1, C4_USB.1, C5_USB.1, CHG_LED.A, D1.5 (VBUS), D2.2 (ANODE), PFMF.050.1.2, Q1.1 (G), R1_PWRUSB.2, U0.4 (VIN), VBUS.TP
VRTC: C8.1, C10_SUPERCAP.2, R_CAPACITOR.1, U3.14 (VBAT)
VUSB: J2.A4, J2.A9, J2.B4, J2.B9, PFMF.050.1.1

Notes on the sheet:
USB C connector & ESD protection
LDO Voltage Regulator
SD Card
ESP32 C6
Battery Charge Level
External NOR Flash 64MB
SPI ESD Protection Lines
Qwiic / Stemma QT
Test Pads
RTC Module DS3231SN
E-Paper Display Header
Display Type Selector
E-Paper Drive Circuit
Li-Po Battery Charging Controller
Environmental Sensor BME688
EPD Power
Voltage Supervisor + Reset & Boot / IO Button
DMG2305UX-7
SD0805S020S1R0
68uH

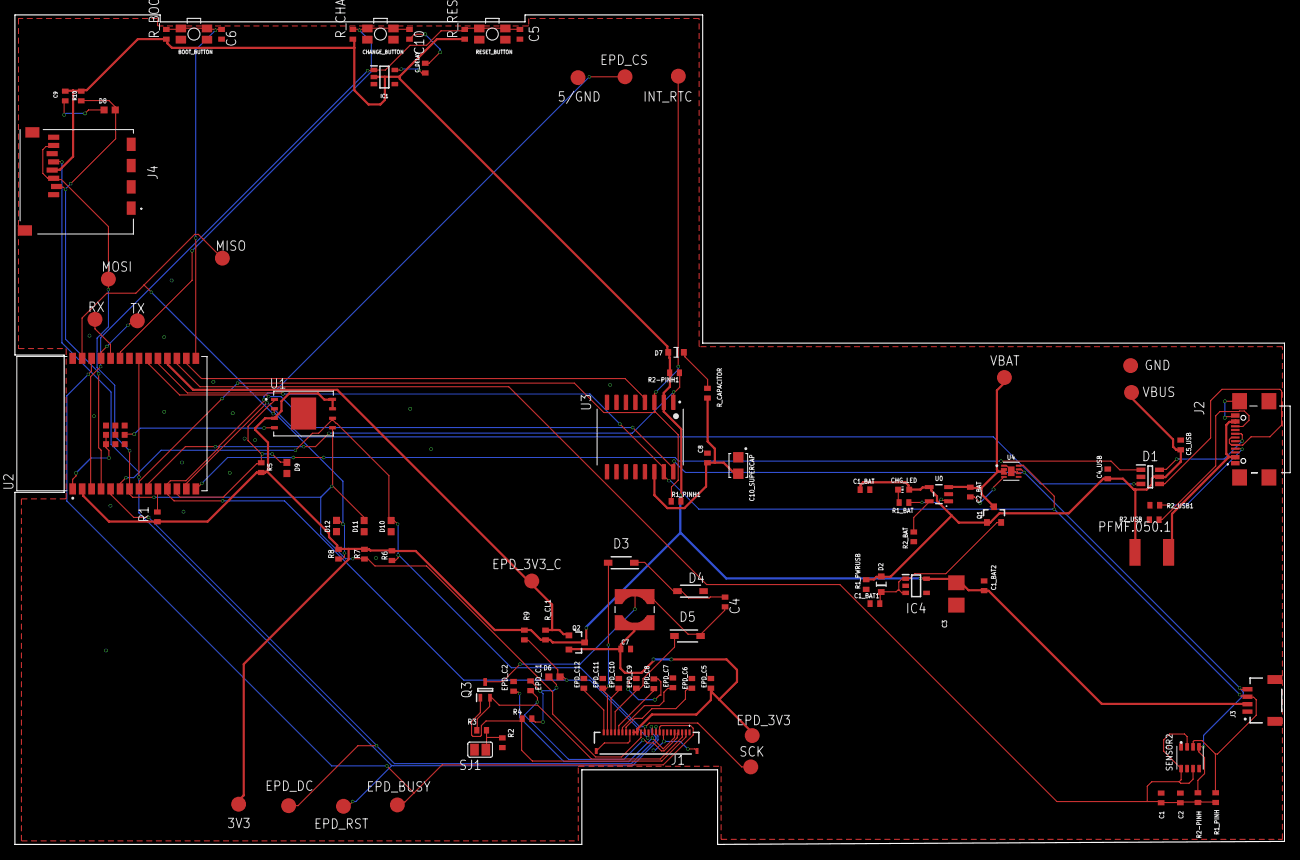
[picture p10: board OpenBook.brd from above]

Board: 2 copper layers, 170.2 x 111.2 mm, 103 parts (0 on the bottom side), 55 nets.

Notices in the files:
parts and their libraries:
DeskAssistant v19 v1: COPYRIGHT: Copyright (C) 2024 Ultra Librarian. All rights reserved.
